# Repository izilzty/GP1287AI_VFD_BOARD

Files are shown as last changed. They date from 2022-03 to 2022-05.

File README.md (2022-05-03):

# GP1287AI_VFD_BOARD
此PCB需搭配型号为GP1287AI的VFD显示屏使用，其他类似型号的屏幕未测试，不保证完全可用，如果要使用请自行检查引脚定义是否相同。

另有增加了此型号VFD屏支持的U8g2库，如有需要请前往 [https://github.com/izilzty/u8g2](https://github.com/izilzty/u8g2) 下载。

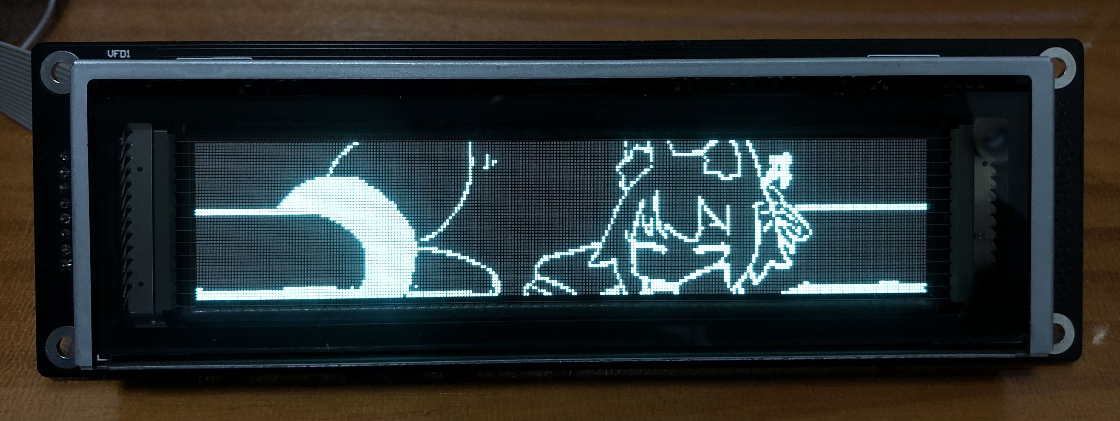
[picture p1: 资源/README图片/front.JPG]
正面


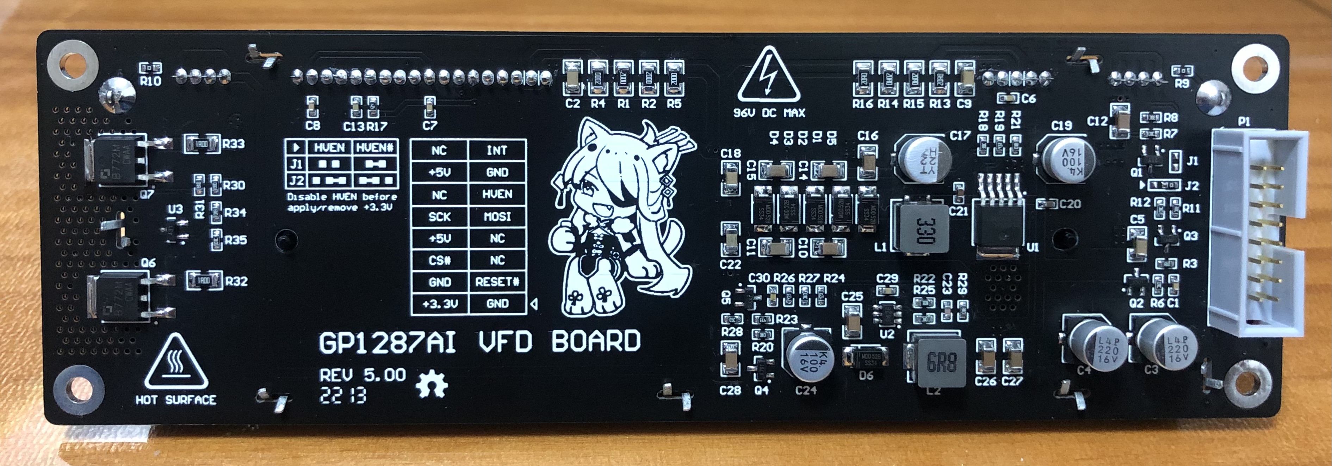
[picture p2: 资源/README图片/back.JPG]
背面


## 硬件说明

### 1. Releases版本内的元件参数
Releases仅用于发布GERBER文件，实际元件参数后期根据情况可能会有调整，所以元件参数请以最新的Main分支为准。

### 2. TL431/432型号选择
非TI品牌、国产购买TL431，TI品牌、仿品购买TL432，主要区别为需要参考电压R在封装的1脚上，购买时请特别注意。

### 3. PCB散热
测试时室温25℃，屏幕满亮度，三极管Q4、Q5以及升压芯片U1的工作时温度约为60度左右，如果将PCB安装在封闭空间内需要注意加强散热，例如增加散热片、在机壳上增加通风孔等。

### 4. PCB电源
* 必须在确保3.3V逻辑电压接通后再在开启高压(HVEN)，如果未接通3.3V逻辑电压时启动高压，则VFD可能会不受控地全屏点亮，造成VFD损坏。
* 5V电源输入电压范围在4.5V到7V内，过低的电压会造成亮度不足，过高的电压会造成输入MOS管损坏和灯丝电压过高。
* 屏幕工作时满亮度全屏点亮电流在2.3A左右，所以推荐至少使用5V 2A电源。
* 如果在同一5V电源输出上同时连接有其他设备，应注意检查屏幕高压(HVEN)开启时是否会过多拉低电源电压。

### 5. VFD灯丝软启动时间调节
更改电阻R28的阻值可以调整软启动时间，阻值越小启动时间越短，一般为10K到12K左右，可以根据电源情况自行调整。

### 6. VFD灯丝偏压
当前灯丝偏压已设置为3V以减少发热和功耗，如果需要使用原板的4.1V偏压需要按照原理图上的提示调整电阻阻值。

### 7. 其他需要注意的问题
* 不要将金属物体掉落在PCB上，以免引起96V高压短路，将96V高压引进逻辑供电部分。
* VFD的13脚(CAP)功能暂时不详，按照原板电路连接了一个电阻和电容，不要更改元件的数值。
* VFD引脚焊接时间不要过长。
* 功率电感型号均为0650一体电感
* PCB上的高压和高温图标为矢量字体，如果不能正常显示则需要安装资源文件夹内的字体然后重启软件即可。

### 8. 版本号说明
PCB版本号格式为：X.YZ
* Z：仅丝印有更改。
* Y：仅线路有更改，但不影响现有的功能。
* X：除丝印和线路以外的其他更改，例如PCB尺寸、通孔位置、元件位置、元件数量等等。

Y和Z相互独立，互不干扰。如果X有改变，则Y和Z全部清0。

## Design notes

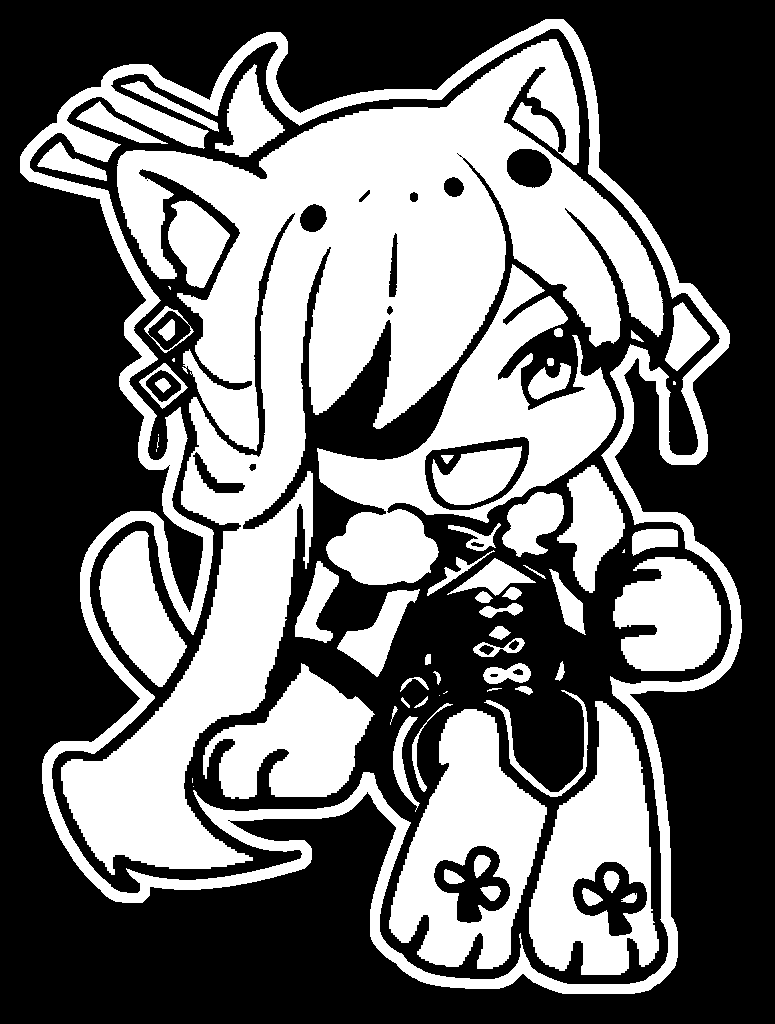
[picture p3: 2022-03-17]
资源/图片/pcb.png

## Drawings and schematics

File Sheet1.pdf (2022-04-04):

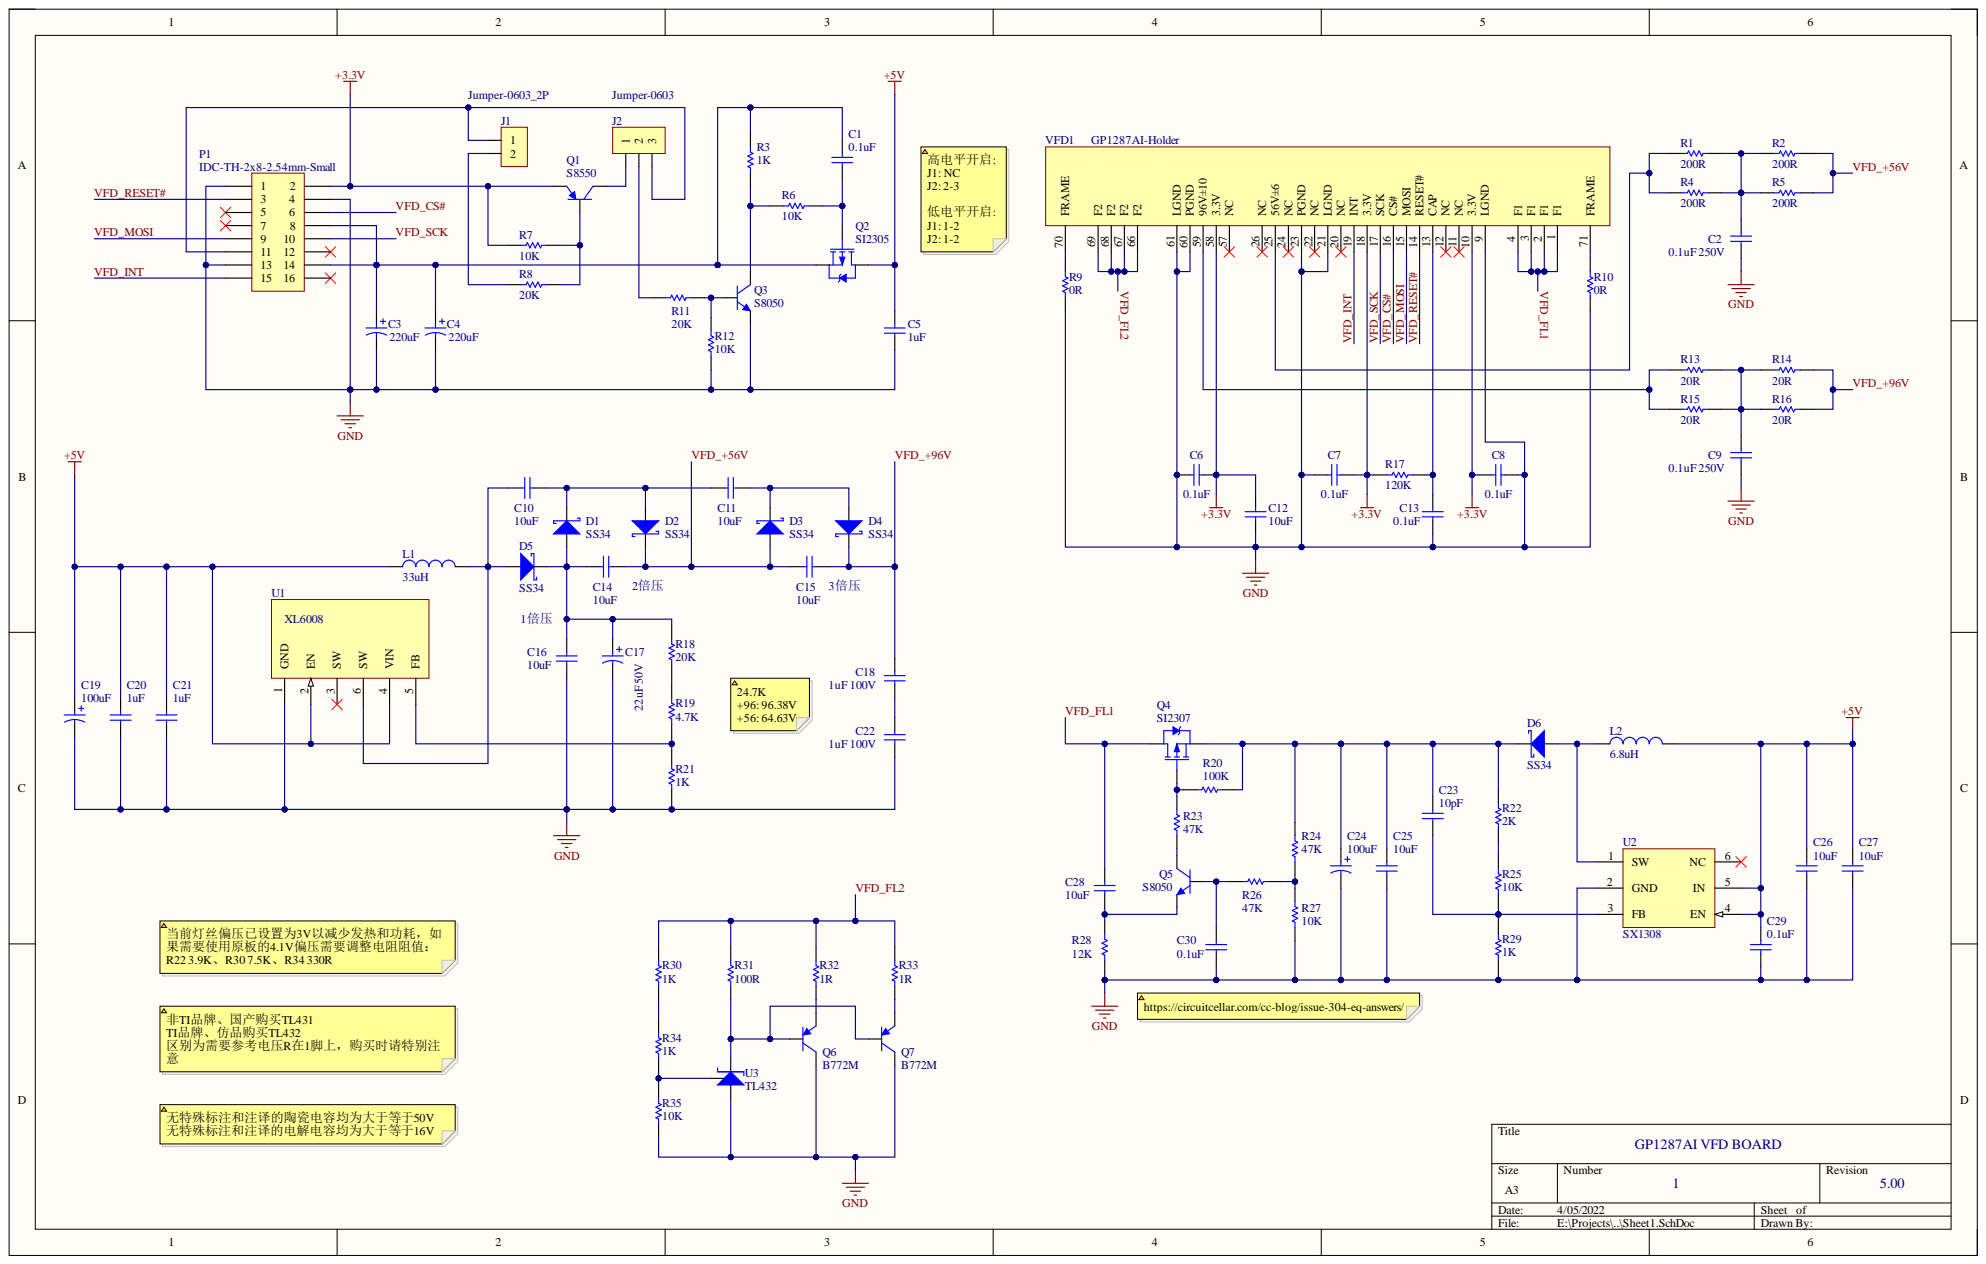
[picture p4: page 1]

LGND 9 3.3V 10 NC 11 NC 12 CAP 13 RESET# 14 MOSI 15 CS# 16 SCK 17 3.3V 18 INT 19 NC 20 LGND 21 NC 22 PGND 23 NC 24 56V±6 25 NC 26

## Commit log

2022-03-13 首次提交
    [GP1287AI_VFD_BOARD.PrjPcb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]
2022-03-13 增加自述文件
2022-03-13 自述文件增加图片
2022-03-13 增加PCB设计资源
2022-03-13 增加字体说明
2022-03-17 增加灯丝软启动
    [GP1287AI_VFD_BOARD.PrjPcb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]
2022-03-18 元件位置微调
    [PCB1.GBL, PCB1.GBO, PCB1.GBP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]
2022-03-18 更新原理图注译
    [GP1287AI_VFD_BOARD.PrjPcb, Sheet1.SchDoc]
2022-03-19 更改元件参数
    [GP1287AI_VFD_BOARD.PrjPcb, Sheet1.SchDoc]
2022-03-22 增加版本号说明
2022-03-24 走线优化
    [GP1287AI_VFD_BOARD.PrjPcb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]
2022-03-24 修改自述文件
2022-03-26 修改软启动元件参数
    [Sheet1.SchDoc]
2022-03-27 修改软启动元件封装
    [GP1287AI_VFD_BOARD.PrjPcb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]
2022-04-04 修改软启动电路参数和自述文件
    [Sheet1.SchDoc]
2022-05-03 增加U8g2库地址
